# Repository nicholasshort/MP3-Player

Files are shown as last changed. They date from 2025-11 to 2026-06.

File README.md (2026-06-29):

# MP3 Player

This is a simple MP3 player designed to be small, lightweight, and long-lasting. The goal is something I can bring on runs, hikes, or long trips that provides 24+ hours of music on a single charge with wired headphones. Firmware is currently in the works, with low level hardware drivers completed.

Assembled board

## Block diagram

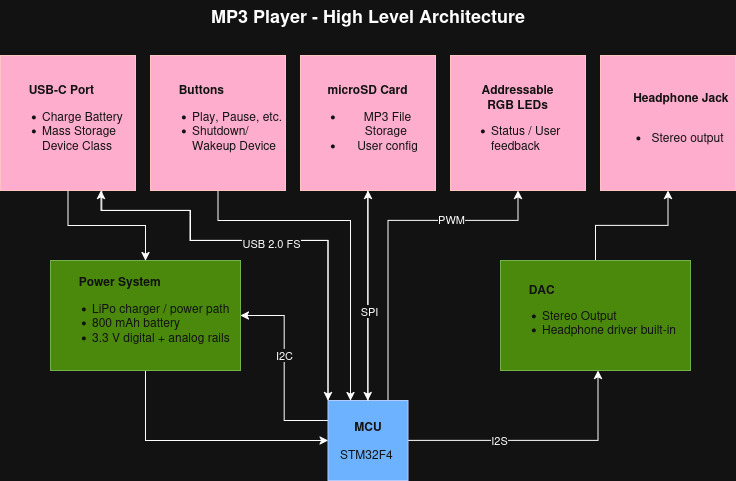
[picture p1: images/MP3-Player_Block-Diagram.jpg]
Block diagram


## Hardware

- **MCU**: STM32F411CEU6 (Cortex-M4F @ 100 MHz, USB OTG FS)
- **DAC**: TI TAD5242 stereo DAC over I²S, 3.5 mm headphone jack
- **Storage**: microSD card (SPI)
- **Power**: USB-C input, TI BQ24259 Li-ion charger, dual TPS7A20 LDOs for analog/digital rails
- **Controls**: 4 tactile switches (PWR, MENU, PLAY, NEXT), 2 × WS2812B-2020 RGB LEDs
- **PCB**: 4-layer, 50 × 50 mm, KiCad

## Repository layout

- `MP3-Player-PCB/` — KiCad project (schematics, board, libraries)
- `MP3-Player-PCB/Manufacturing/` — Gerbers, BOM, and pick-and-place files for JLCPCB
- `MP3-Player-Firmware/` — STM32CubeIDE project
- `images/` — Photos of the board

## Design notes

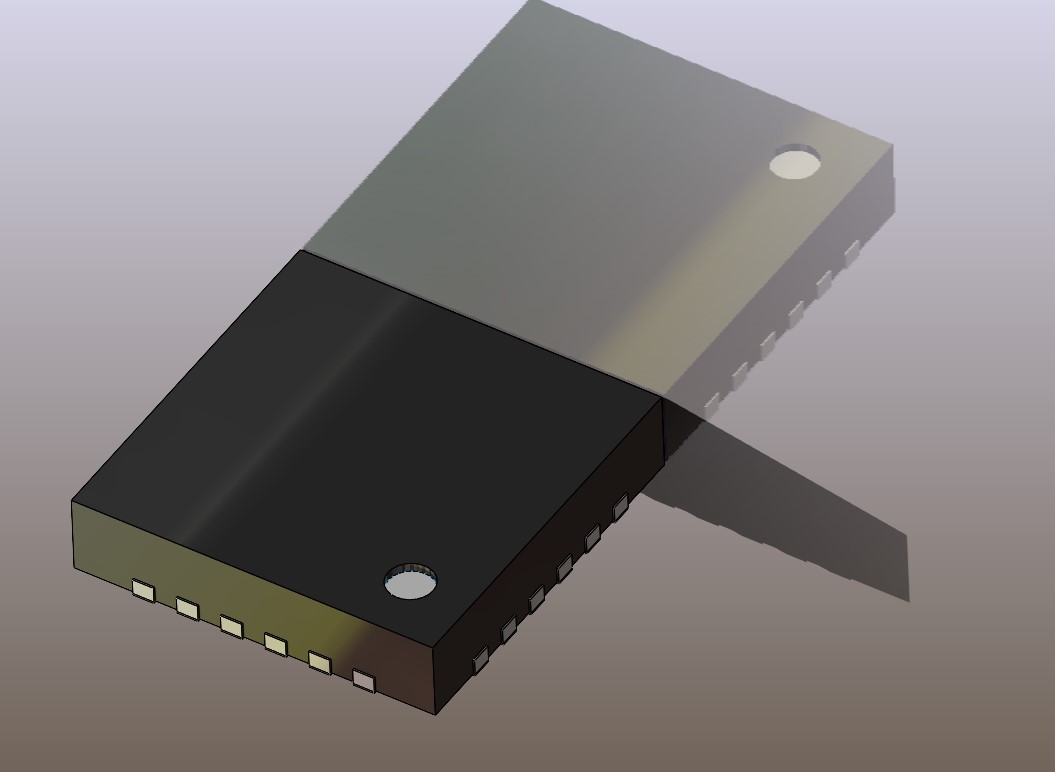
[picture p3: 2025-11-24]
MP3-Player-PCB/3D Models/qfn-24-1.snapshot.1/QFN 24.jpg

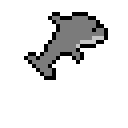
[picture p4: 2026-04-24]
MP3-Player-PCB/Silkscreen Images/Bluesk.png

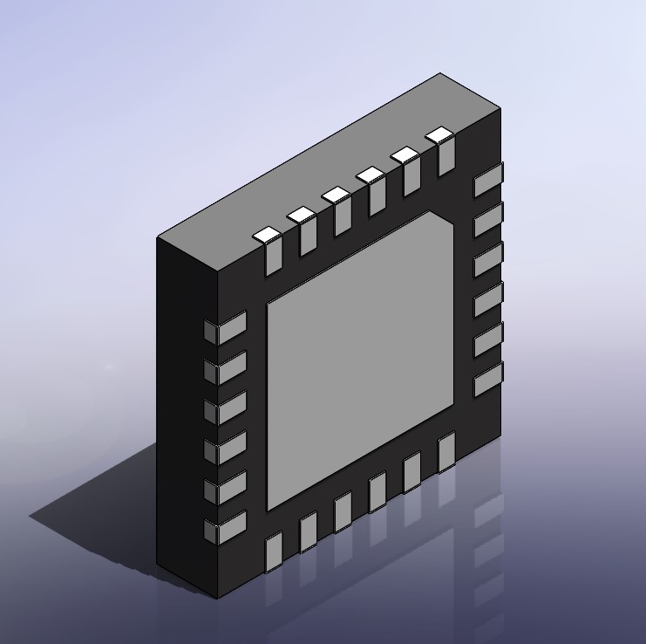
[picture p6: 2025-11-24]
MP3-Player-PCB/3D Models/qfn-24-1.snapshot.1/OFN24.jpg

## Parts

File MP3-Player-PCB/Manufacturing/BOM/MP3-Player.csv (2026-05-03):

Reference | Qty | Footprint | Value | JLCPCB Part #
Y101 | 1 | Crystal:Crystal_SMD_3225-4Pin_3.2x2.5mm | 8MHz | C518154
U401 | 1 | MP3-Player_Footprint_Libraries:TAD5242 | TAD5242 | C42414591
U301,U403 | 2 | Package_TO_SOT_SMD:SOT-23-6 | TPD4E1U06 | C124691
U203,U204 | 2 | Package_TO_SOT_SMD:SOT-23-5 | TPS7A2033PDBVR | C2862740
U202 | 1 | Package_TO_SOT_SMD:SOT-23-6 | USBLC6-2SC6 | C7519
U201 | 1 | Package_DFN_QFN:VQFN-24-1EP_4x4mm_P0.5mm_EP2.5x2.5mm | BQ24259 | C473366
U101 | 1 | Package_DFN_QFN:QFN-48-1EP_7x7mm_P0.5mm_EP5.6x5.6mm | STM32F411CEUx | C2054095
TH201 | 1 | Resistor_SMD:R_0603_1608Metric | NTC | C700814
SW301,SW302,SW303,SW304 | 4 | MP3-Player_Footprint_Libraries:ZX-QC66 | ZX-QC66-10.0TP | C7470162
R305,R306,R307 | 3 | Resistor_SMD:R_0402_1005Metric | 0R | C17168
R217 | 1 | Resistor_SMD:R_0402_1005Metric | 31.6k | C11463
R216 | 1 | Resistor_SMD:R_0402_1005Metric | 200k | C25764
R214 | 1 | Resistor_SMD:R_0402_1005Metric | 100k | C25741
R209,R210,R213,R215,R301,R302,R303,R304,R308,R310,R311,R312,R315 | 13 | Resistor_SMD:R_0402_1005Metric | 56k | C25796
R208 | 1 | Resistor_SMD:R_0402_1005Metric | 316R | C247119
R207 | 1 | Resistor_SMD:R_0402_1005Metric | 5.23k | C25907
R205,R206 | 2 | Resistor_SMD:R_0402_1005Metric | 5.1k | C25905
R202,R203,R204,R309,R313,R314 | 6 | Resistor_SMD:R_0402_1005Metric | 220k | C25546
R103,R104 | 2 | Resistor_SMD:R_0402_1005Metric | 1k | C11702
R102,R201 | 2 | Resistor_SMD:R_0603_1608Metric | 0R | C15402
R101,R211,R212 | 3 | Resistor_SMD:R_0402_1005Metric | 10k | C25744
Q302,Q305 | 2 | Package_TO_SOT_SMD:SOT-23 | 2N7002H | C3290631
Q301,Q303,Q304 | 3 | Package_TO_SOT_SMD:SOT-23 | AO3401A | C15127
L201 | 1 | Inductor_SMD:L_Sunlord_SWPA3015S | 1u | C43388
J402 | 1 | MP3-Player_Footprint_Libraries:PJ-320B | PJ-320B | C18594
J301 | 1 | MP3-Player_Footprint_Libraries:TF-015 | Micro_SD_Card_Det1 | C113206
J202 | 1 | Connector_USB:USB_C_Receptacle_HRO_TYPE-C-31-M-12 | USB_C_Receptacle_USB2.0_16P | C165948
J201 | 1 | Connector_Molex:Molex_PicoBlade_53048-0210_1x02_P1.25mm_Horizontal | Conn_01x02_Socket | C505099
FB201 | 1 | Inductor_SMD:L_0805_2012Metric | 120R | C5671
D301,D302 | 2 | LED_SMD:LED_WS2812B-2020_PLCC4_2.0x2.0mm | WS2812B-2020 | C965555
D102 | 1 | LED_SMD:LED_0402_1005Metric | BLUE | C131223
D101 | 1 | LED_SMD:LED_0402_1005Metric | GREEN | C74338
C205,C206,C207,C208,C210,C214,C215,C216,C217 | 9 | Capacitor_SMD:C_0805_2012Metric | 10u | C15850
C204 | 1 | Capacitor_SMD:C_0402_1005Metric | 47n | C82219
C203,C209,C211,C212,C213,C301,C304,C305,C401,C404,C405,C406 | 12 | Capacitor_SMD:C_0603_1608Metric | 10u | C19702
C113,C114 | 2 | Capacitor_SMD:C_0603_1608Metric | 10p | C162202
C102,C103,C104,C105,C106,C107,C108,C109,C110,C111,C112,C201,C202,C302,C303,C402,C403,C407 | 18 | Capacitor_SMD:C_0402_1005Metric | 100n | C1525
C101,C115 | 2 | Capacitor_SMD:C_0603_1608Metric | 4.7u | C1705

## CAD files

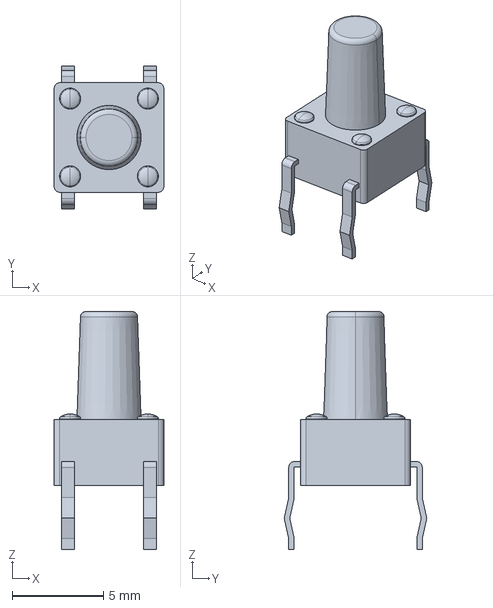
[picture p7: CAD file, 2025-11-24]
MP3-Player-PCB/3D Models/1_1825910_4/c-1-1825910-4-c-3d.stp
5.99 x 7.80 x 13.0 mm

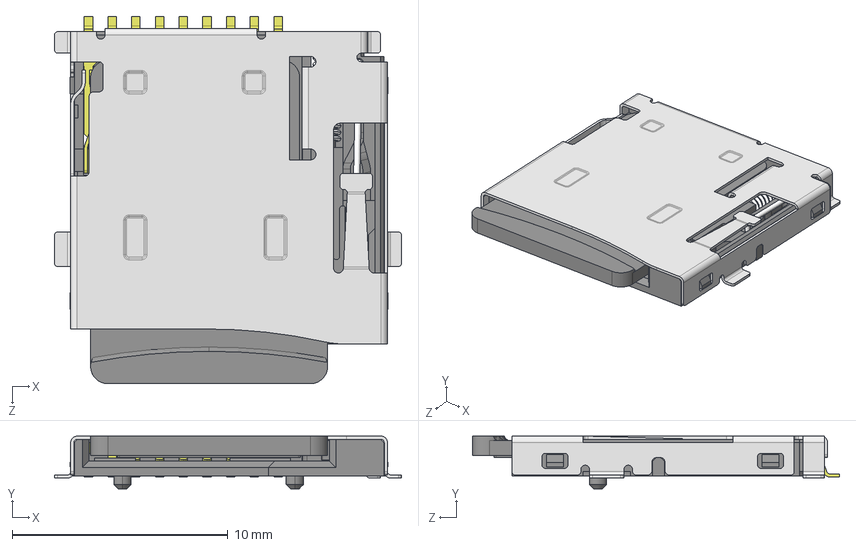
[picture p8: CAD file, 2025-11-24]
MP3-Player-PCB/3D Models/microsd-socket-slot-like-tfp09-2-12b-tf-01a-etc-1.snapshot.1/MicroSD_Socket.STEP
16.1 x 2.45 x 17.0 mm
Case^MicroSD_Socket
Insert^MicroSD_Socket
Brace^MicroSD_Socket
Spring^MicroSD_Socket
Lid^MicroSD_Socket
Pin_Middle^MicroSD_Socket x 5
Pin_Short^MicroSD_Socket
Pin_Long^MicroSD_Socket x 2
MicroSD_Card^MicroSD_Socket
Pin_CardIn^MicroSD_Socket

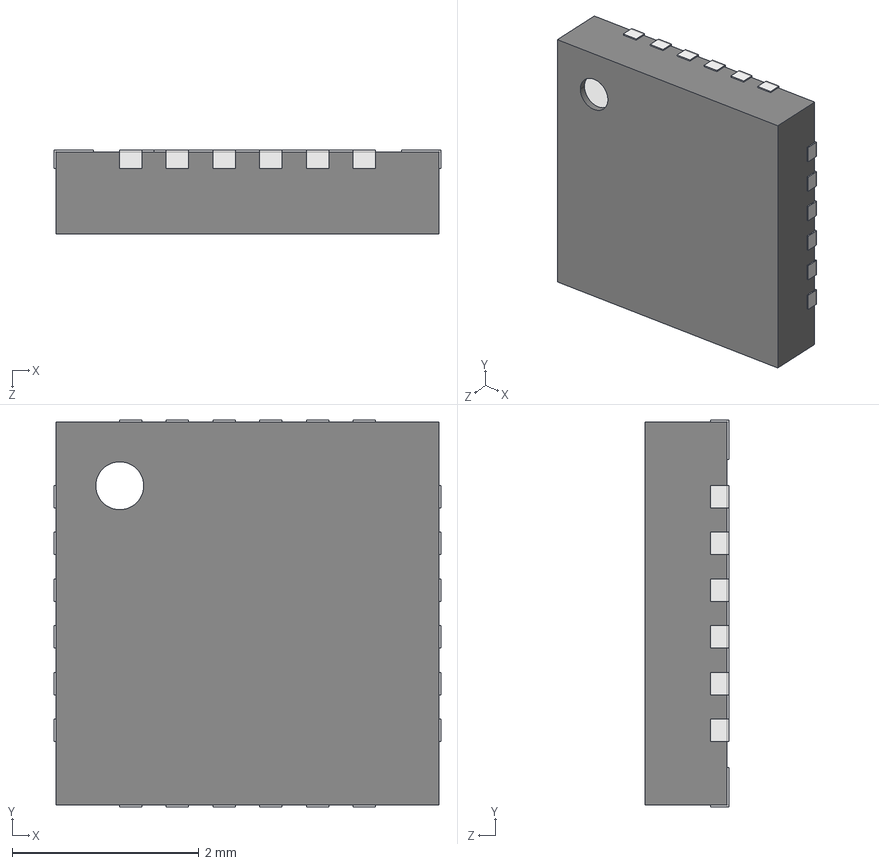
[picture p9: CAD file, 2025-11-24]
MP3-Player-PCB/3D Models/qfn-24-1.snapshot.1/QFN 24.STEP
4.14 x 4.14 x 0.9 mm
Open_CASCADE_STEP_translator_6.8_11.2.1.step_Varsay考an
Open_CASCADE_STEP_translator_6.8_11.4.1.step_Varsay考an x 24
Open_CASCADE_STEP_translator_6.8_11.1.step_Varsay考an
Thermal_Shape.step_Varsay考an

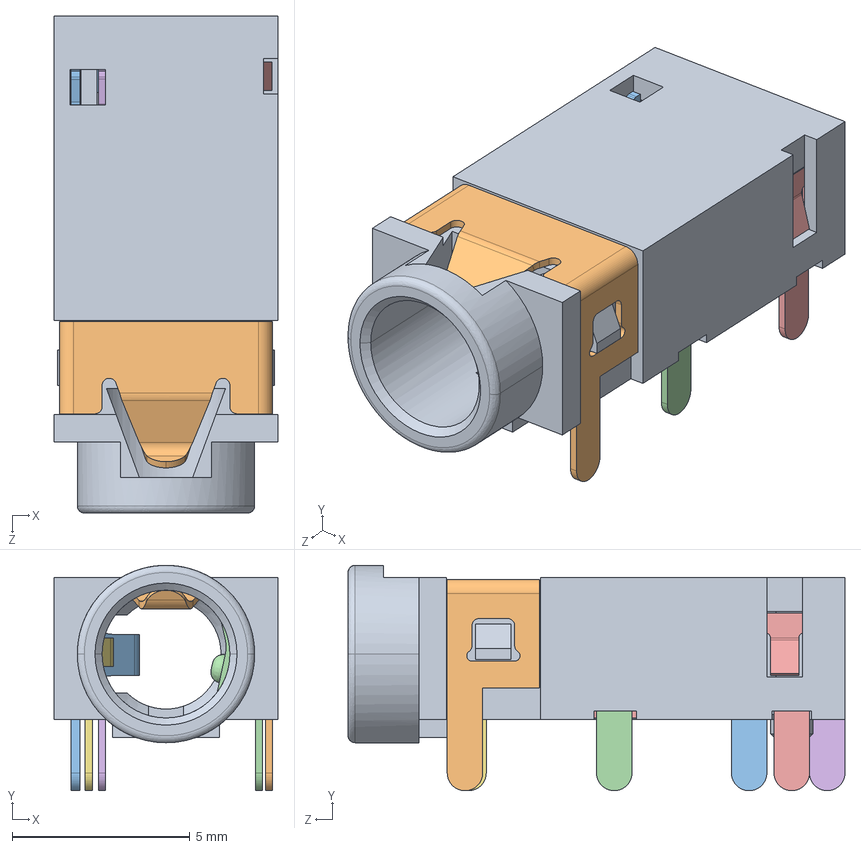
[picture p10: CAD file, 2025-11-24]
MP3-Player-PCB/3D Models/Similar Audio Jack Connector/54-00176.STEP
6.30 x 6.35 x 14.0 mm
54-00176_insulator
54-00176_#1
54-00176_#4
54-00176_#3
54-00176_#6
54-00176_#5
54-00176_#2

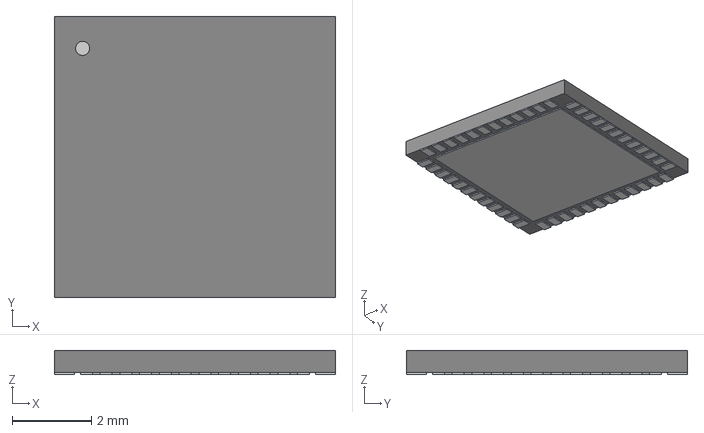
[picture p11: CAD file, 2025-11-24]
MP3-Player-PCB/3D Models/STM32F411CEU6/UFQFPN-48_7X7X0P55MM.step
7.11 x 7.11 x 0.612 mm

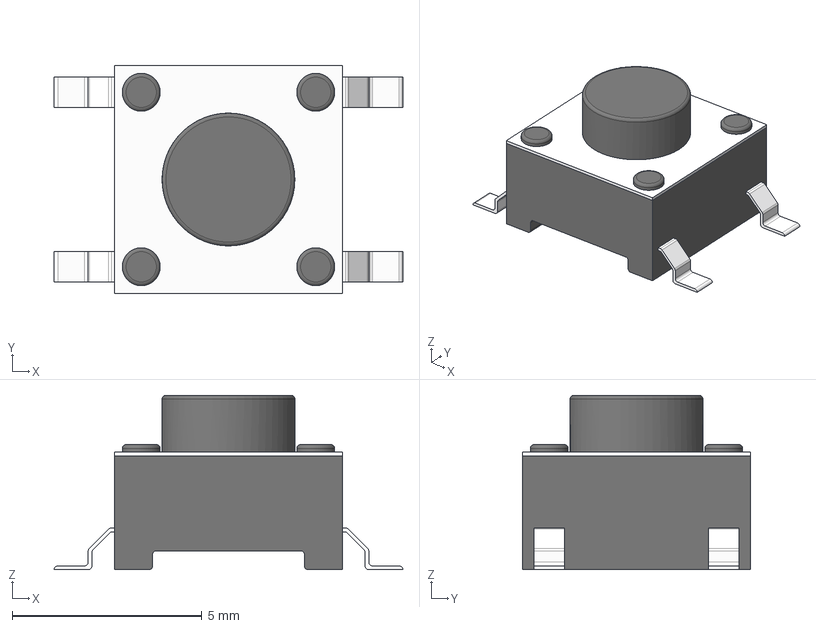
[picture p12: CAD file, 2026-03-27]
MP3-Player-PCB/3D Models/tact-switch-smd-6x6mm-x-4-5mm-1.snapshot.1/tact switch SMD 6x6 mm x 4,5mm.step
9.20 x 6.00 x 4.60 mm

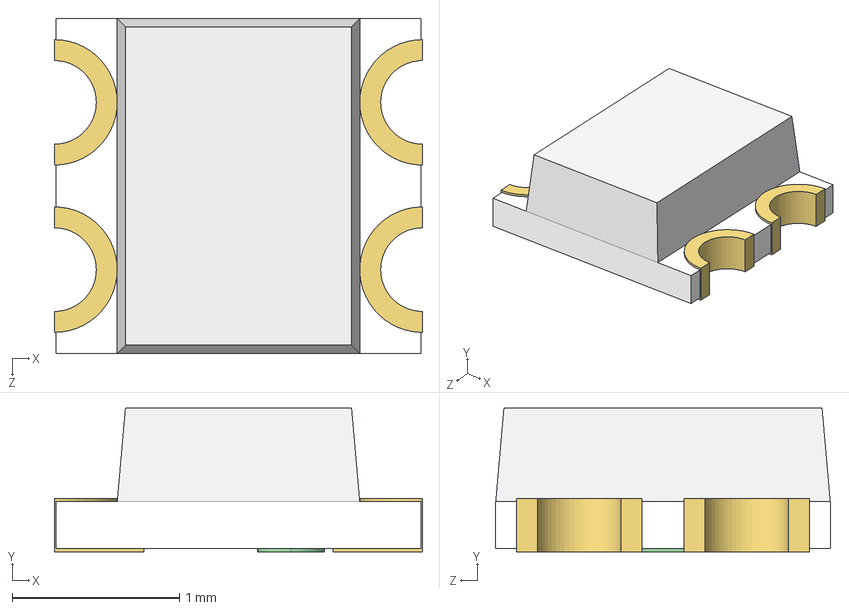
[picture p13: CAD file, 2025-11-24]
MP3-Player-PCB/3D Models/ws2812-2020-1.snapshot.4/WS2812-2020.STEP
2.20 x 0.86 x 2.00 mm

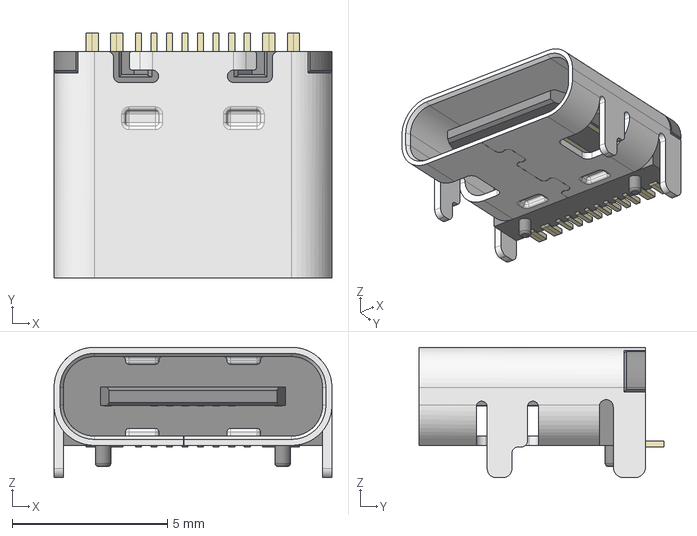
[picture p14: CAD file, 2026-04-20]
MP3-Player-PCB/3D Models/HRO_TYPE-C-31-M-12.step
8.95 x 7.90 x 4.20 mm

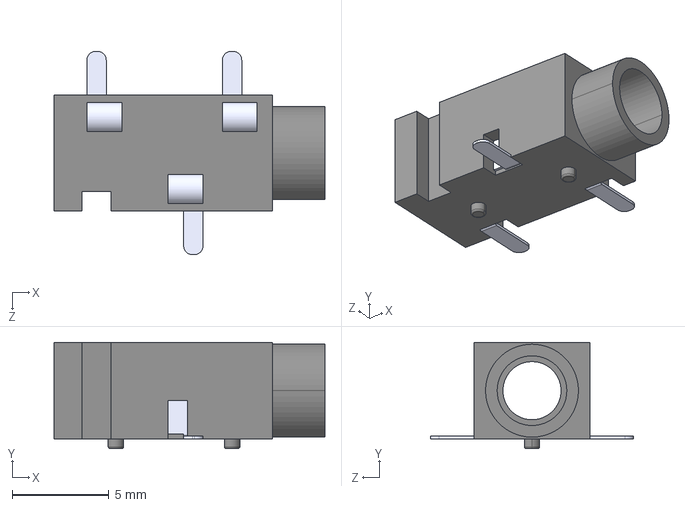
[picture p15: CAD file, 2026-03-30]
MP3-Player-PCB/3D Models/PJ-320B--3DModel-STEP-56544.STEP
14.0 x 5.50 x 10.5 mm

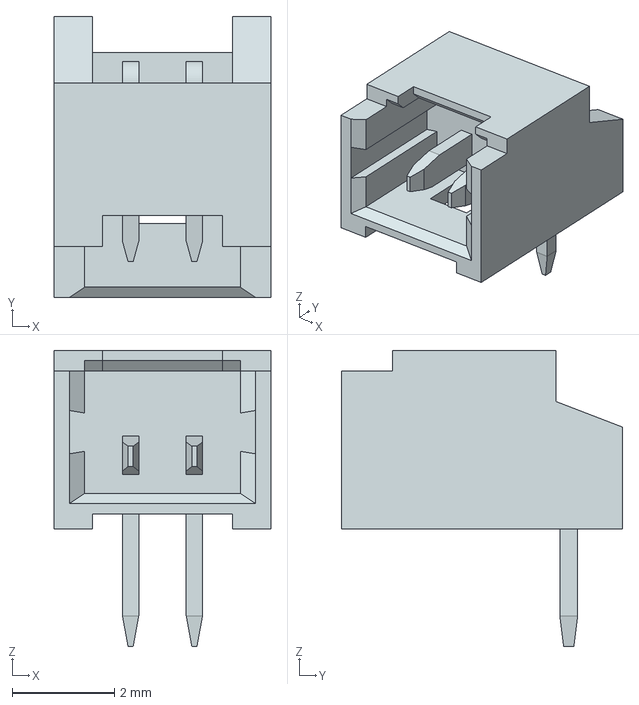
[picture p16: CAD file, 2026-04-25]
MP3-Player-PCB/3D Models/530480210.stp
4.25 x 5.50 x 5.80 mm

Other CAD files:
MP3-Player-PCB/3D Models/ws2812-2020-1.snapshot.4/WS2812-2020.SLDPRT

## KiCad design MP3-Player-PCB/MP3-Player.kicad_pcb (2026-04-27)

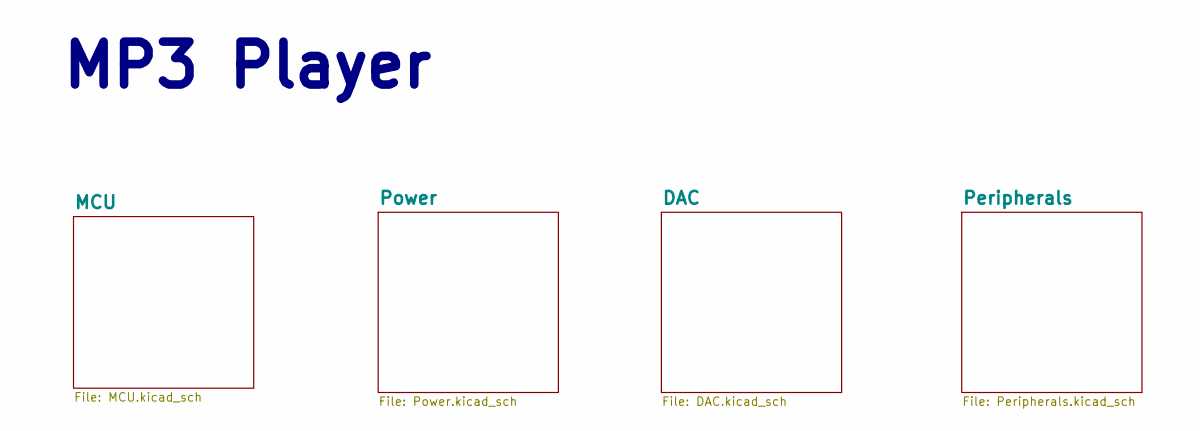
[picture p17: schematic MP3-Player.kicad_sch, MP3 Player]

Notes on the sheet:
MP3 Player

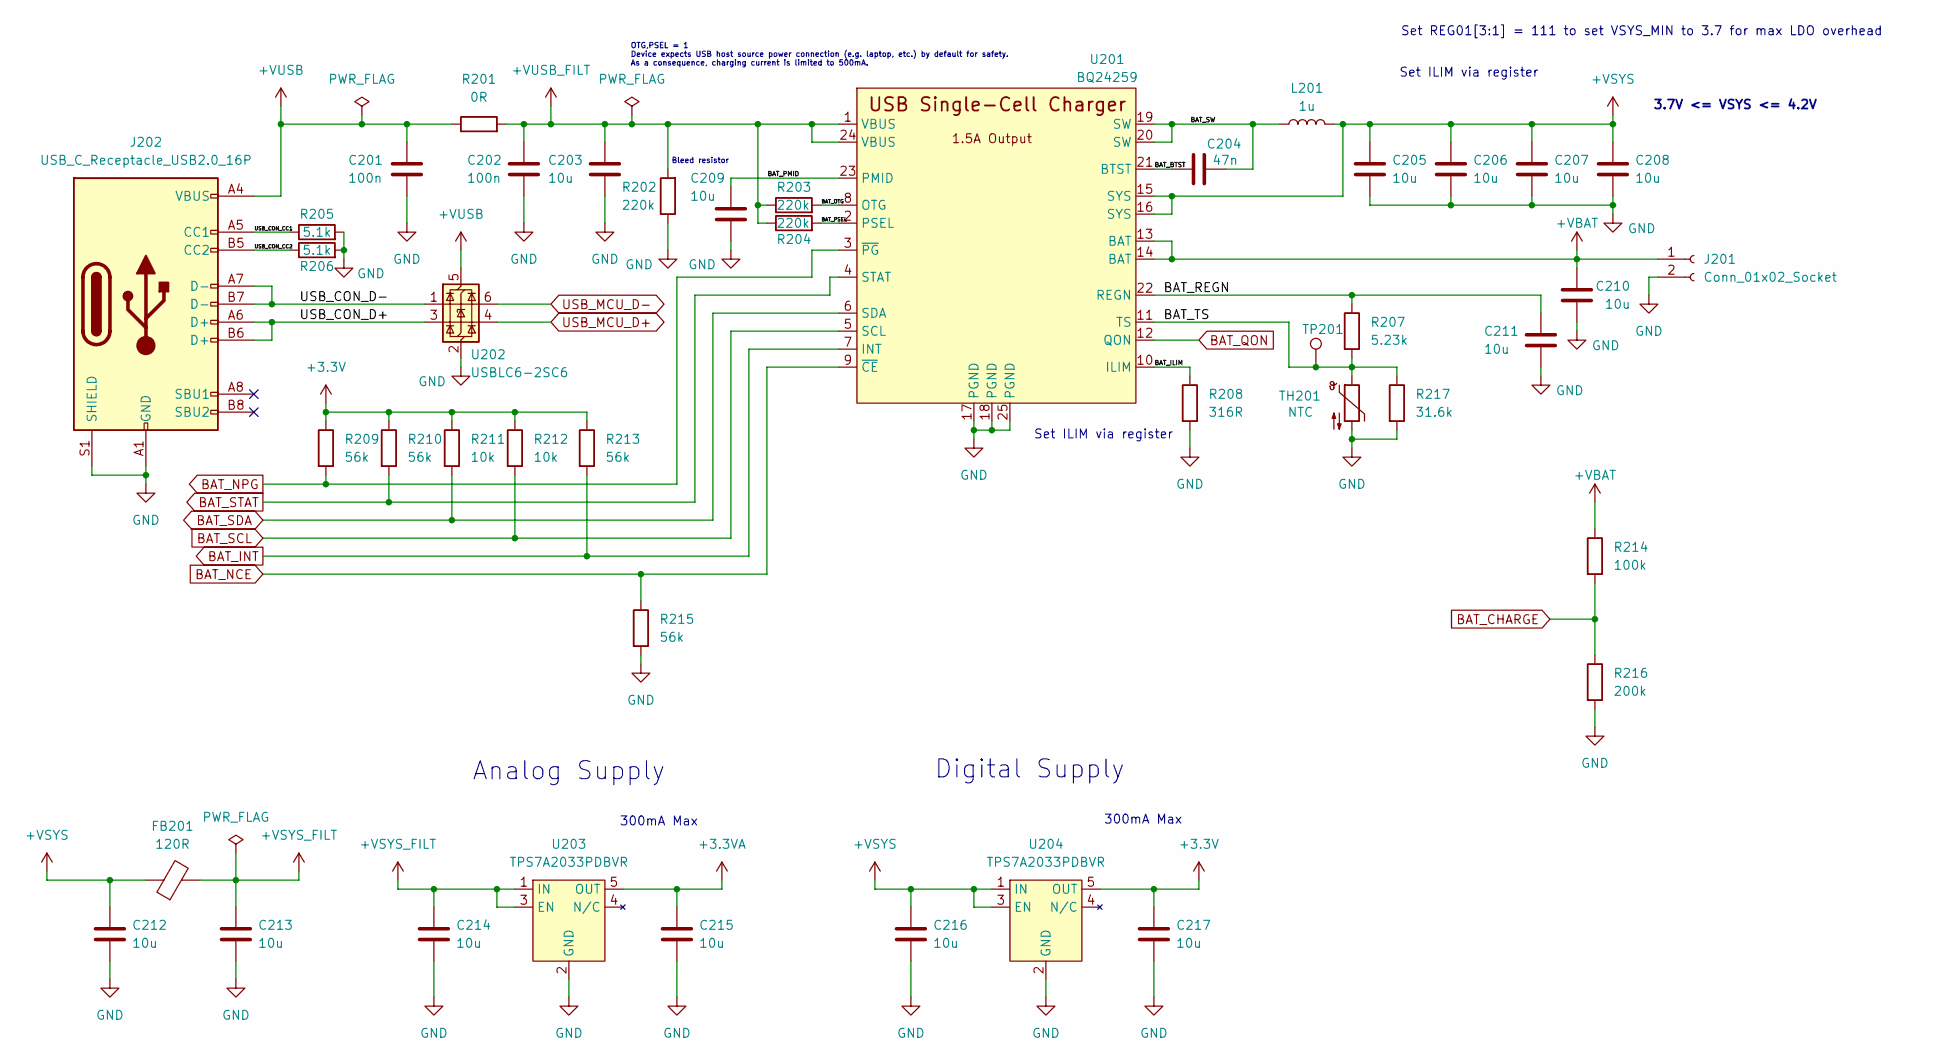
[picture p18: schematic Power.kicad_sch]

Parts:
C201, C202: 100n; C_0402_1005Metric; JLCPCB Part # C1525
C203, C209, C211, C212, C213: 10u; C_0603_1608Metric; JLCPCB Part # C19702
C204: 47n; C_0402_1005Metric; JLCPCB Part # C82219
C205, C206, C207, C208, C210, C214, C215, C216, C217: 10u; C_0805_2012Metric; JLCPCB Part # C15850
FB201: 120R; L_0805_2012Metric; JLCPCB Part # C5671
J201: Conn_01x02_Socket; Molex_PicoBlade_53048-0210_1x02_P1.25mm_Horizontal; JLCPCB Part # C505099
J202: USB_C_Receptacle_USB2.0_16P; USB_C_Receptacle_HRO_TYPE-C-31-M-12; JLCPCB Part # C165948
L201: 1u; L_Sunlord_SWPA3015S; JLCPCB Part # C43388
R201: 0R; R_0603_1608Metric; JLCPCB Part # C15402
R202, R203, R204: 220k; R_0402_1005Metric; JLCPCB Part # C25546
R205, R206: 5.1k; R_0402_1005Metric; JLCPCB Part # C25905
R207: 5.23k; R_0402_1005Metric; JLCPCB Part # C25907
R208: 316R; R_0402_1005Metric; JLCPCB Part # C247119
R209, R210, R213, R215: 56k; R_0402_1005Metric; JLCPCB Part # C25796
R211, R212: 10k; R_0402_1005Metric; JLCPCB Part # C25744
R214: 100k; R_0402_1005Metric; JLCPCB Part # C25741
R216: 200k; R_0402_1005Metric; JLCPCB Part # C25764
R217: 31.6k; R_0402_1005Metric; JLCPCB Part # C11463
TH201: NTC; R_0603_1608Metric; JLCPCB Part # C700814
TP201: TestPoint; TestPoint_Pad_1.0x1.0mm
U201: BQ24259; VQFN-24-1EP_4x4mm_P0.5mm_EP2.5x2.5mm; JLCPCB Part # C473366
U202: USBLC6-2SC6; SOT-23-6; JLCPCB Part # C7519
U203, U204: TPS7A2033PDBVR; SOT-23-5; JLCPCB Part # C2862740

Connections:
+3.3V: C217.1, R209.1, R210.1, R211.1, R212.1, R213.1, U204.5 (OUT); also elsewhere on the board
+3.3VA: C215.1, U203.5 (OUT); also elsewhere on the board
+VBAT: C210.1, J201.1, R214.1, U201.13 (BAT), U201.14 (BAT); also elsewhere on the board
+VSYS: C205.1, C206.1, C207.1, C208.1, C212.1, C216.1, FB201.1, L201.2, U201.15 (SYS), U201.16 (SYS), U204.1 (IN), U204.3 (EN); also elsewhere on the board
+VSYS_FILT: C213.1, C214.1, FB201.2, U203.1 (IN), U203.3 (EN)
+VUSB: C201.1, J202.A4 (VBUS), J202.A9 (VBUS), J202.B4 (VBUS), J202.B9 (VBUS), R201.1, U202.5 (VBUS)
+VUSB_FILT: C202.1, C203.1, R201.2, R202.2, R203.1, R204.1, U201.1 (VBUS), U201.24 (VBUS)
/Power/BAT_BTST: C204.1, U201.21 (BTST)
/Power/BAT_ILIM: R208.1, U201.10 (ILIM)
/Power/BAT_OTG: R203.2, U201.8 (OTG)
/Power/BAT_PMID: C209.1, U201.23 (PMID)
/Power/BAT_PSEL: R204.2, U201.2 (PSEL)
/Power/BAT_REGN: C211.1, R207.1, U201.22 (REGN)
/Power/BAT_SW: C204.2, L201.1, U201.19 (SW), U201.20 (SW)
/Power/BAT_TS: R207.2, R217.1, TH201.1, TP201.1, U201.11 (TS)
/Power/USB_CON_CC1: J202.A5 (CC1), R205.1
/Power/USB_CON_CC2: J202.B5 (CC2), R206.1
/Power/USB_CON_D+: J202.A6 (D+), J202.B6 (D+), U202.3 (I/O2)
/Power/USB_CON_D-: J202.A7 (D-), J202.B7 (D-), U202.1 (I/O1)
BAT_CHARGE: R214.2, R216.1; also elsewhere on the board
BAT_INT: R213.2, U201.7 (INT); also elsewhere on the board
BAT_NCE: R215.1, U201.9 (~CE); also elsewhere on the board
BAT_NPG: R209.2, U201.3 (~PG); also elsewhere on the board
BAT_QON: U201.12 (QON); also elsewhere on the board
BAT_SCL: R212.2, U201.5 (SCL); also elsewhere on the board
BAT_SDA: R211.2, U201.6 (SDA); also elsewhere on the board
BAT_STAT: R210.2, U201.4 (STAT); also elsewhere on the board
GND: C201.2, C202.2, C203.2, C205.2, C206.2, C207.2, C208.2, C209.2, C210.2, C211.2, C212.2, C213.2, C214.2, C215.2, C216.2, C217.2, J201.2, J202.A1 (GND), J202.A12 (GND), J202.B1 (GND), J202.B12 (GND), J202.S1 (SHIELD), R202.1, R205.2, R206.2, R208.2, R215.2, R216.2, R217.2, TH201.2, U201.17 (PGND), U201.18 (PGND), U201.25 (PGND), U202.2 (GND), U203.2 (GND), U204.2 (GND); also elsewhere on the board
USB_MCU_D+: U202.4 (I/O2); also elsewhere on the board
USB_MCU_D-: U202.6 (I/O1); also elsewhere on the board

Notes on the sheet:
Analog Supply
Set ILIM via register
Bleed resistor
300mA Max
Digital Supply
OTG,PSEL = 1 Device expects USB host source power connection (e.g. laptop, etc.) by default for safety. As a consequence, charging current is limited to 500mA.
3.7V <= VSYS <= 4.2V
Set REG01[3:1] = 111 to set VSYS_MIN to 3.7 for max LDO overhead

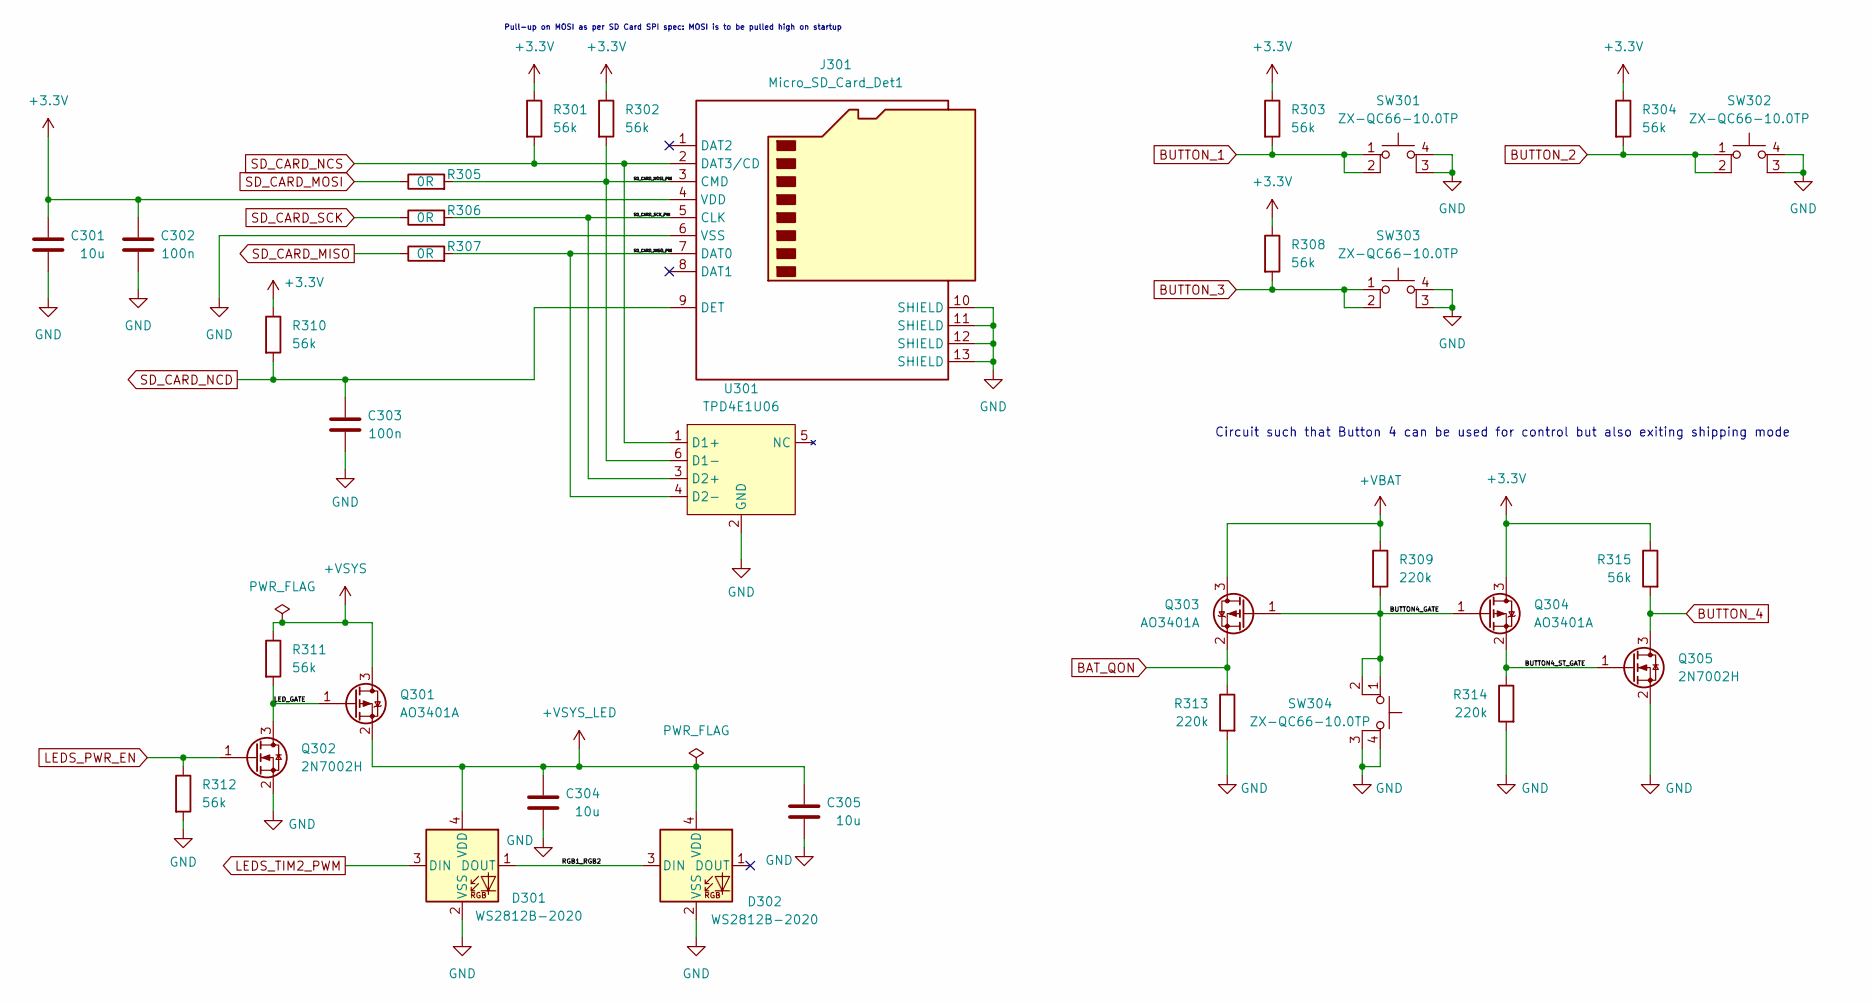
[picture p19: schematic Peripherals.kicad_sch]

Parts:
C301, C304, C305: 10u; C_0603_1608Metric; JLCPCB Part # C19702
C302, C303: 100n; C_0402_1005Metric; JLCPCB Part # C1525
D301, D302: WS2812B-2020; LED_WS2812B-2020_PLCC4_2.0x2.0mm; JLCPCB Part # C965555
J301: Micro_SD_Card_Det1; TF-015; JLCPCB Part # C113206
Q301, Q303, Q304: AO3401A; SOT-23; JLCPCB Part # C15127
Q302, Q305: 2N7002H; SOT-23; JLCPCB Part # C3290631
R301, R302, R303, R304, R308, R310, R311, R312, R315: 56k; R_0402_1005Metric; JLCPCB Part # C25796
R305, R306, R307: 0R; R_0402_1005Metric; JLCPCB Part # C17168
R309, R313, R314: 220k; R_0402_1005Metric; JLCPCB Part # C25546
SW301, SW302, SW303, SW304: ZX-QC66-10.0TP; ZX-QC66; JLCPCB Part # C7470162
U301: TPD4E1U06; SOT-23-6; JLCPCB Part # C124691

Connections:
+3.3V: C301.1, C302.1, J301.4 (VDD), Q304.3 (D), R301.1, R302.1, R303.1, R304.1, R308.1, R310.1, R315.1; also elsewhere on the board
+VBAT: Q303.3 (D), R309.1; also elsewhere on the board
+VSYS: Q301.3 (D), R311.1; also elsewhere on the board
+VSYS_LED: C304.1, C305.1, D301.4 (VDD), D302.4 (VDD), Q301.2 (S)
/Peripherals/BUTTON4_GATE: Q303.1 (G), Q304.1 (G), R309.2, SW304.1, SW304.2
/Peripherals/BUTTON4_ST_GATE: Q304.2 (S), Q305.1 (G), R314.1
/Peripherals/LED_GATE: Q301.1 (G), Q302.3 (D), R311.2
/Peripherals/RGB1_RGB2: D301.1 (DOUT), D302.3 (DIN)
/Peripherals/SD_CARD_MISO_PIN: J301.7 (DAT0), R307.2, U301.4 (D2-)
/Peripherals/SD_CARD_MOSI_PIN: J301.3 (CMD), R302.2, R305.2, U301.6 (D1-)
/Peripherals/SD_CARD_SCK_PIN: J301.5 (CLK), R306.2, U301.3 (D2+)
BAT_QON: Q303.2 (S), R313.1; also elsewhere on the board
BUTTON_1: R303.2, SW301.1, SW301.2; also elsewhere on the board
BUTTON_2: R304.2, SW302.1, SW302.2; also elsewhere on the board
BUTTON_3: R308.2, SW303.1, SW303.2; also elsewhere on the board
BUTTON_4: Q305.3 (D), R315.2; also elsewhere on the board
GND: C301.2, C302.2, C303.2, C304.2, C305.2, D301.2 (VSS), D302.2 (VSS), J301.6 (VSS), J301.10 (SHIELD), J301.11 (SHIELD), J301.12 (SHIELD), J301.13 (SHIELD), Q302.2 (S), Q305.2 (S), R312.2, R313.2, R314.2, SW301.3 (K), SW301.4 (A), SW302.3 (K), SW302.4 (A), SW303.3 (K), SW303.4 (A), SW304.3 (K), SW304.4 (A), U301.2 (GND); also elsewhere on the board
LEDS_PWR_EN: Q302.1 (G), R312.1; also elsewhere on the board
LEDS_TIM2_PWM: D301.3 (DIN); also elsewhere on the board
SD_CARD_MISO: R307.1; also elsewhere on the board
SD_CARD_MOSI: R305.1; also elsewhere on the board
SD_CARD_NCD: C303.1, J301.9 (DET), R310.2; also elsewhere on the board
SD_CARD_NCS: J301.2 (DAT3/CD), R301.2, U301.1 (D1+); also elsewhere on the board
SD_CARD_SCK: R306.1; also elsewhere on the board

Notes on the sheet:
Circuit such that Button 4 can be used for control but also exiting shipping mode
Pull-up on MOSI as per SD Card SPI spec: MOSI is to be pulled high on startup

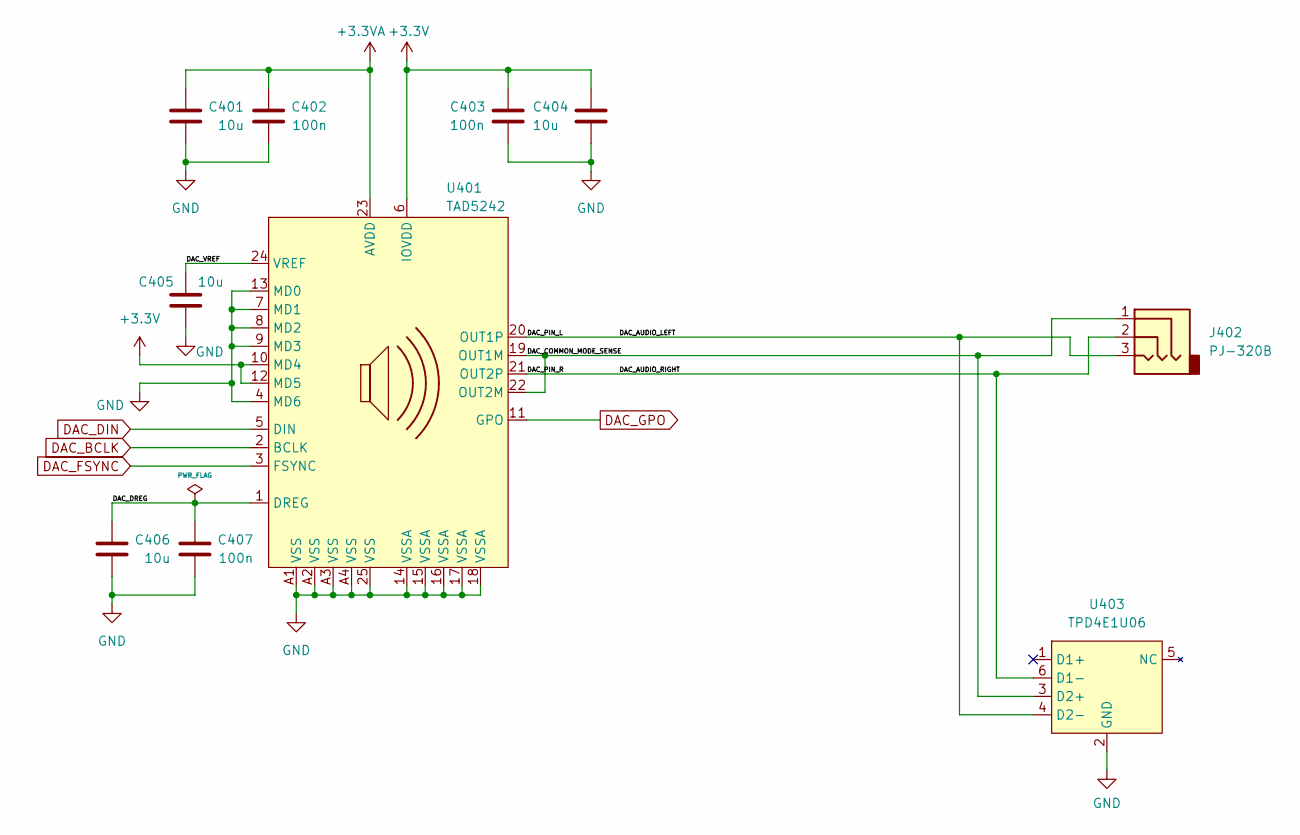
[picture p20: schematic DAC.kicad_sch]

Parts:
C401, C404, C405, C406: 10u; C_0603_1608Metric; JLCPCB Part # C19702
C402, C403, C407: 100n; C_0402_1005Metric; JLCPCB Part # C1525
J402: PJ-320B; JLCPCB Part # C18594
U401: TAD5242; JLCPCB Part # C42414591
U403: TPD4E1U06; SOT-23-6; JLCPCB Part # C124691

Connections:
+3.3V: C403.1, C404.1, U401.6 (IOVDD), U401.10 (MD4), U401.12 (MD5); also elsewhere on the board
+3.3VA: C401.1, C402.1, U401.23 (AVDD); also elsewhere on the board
/DAC/DAC_AUDIO_LEFT: J402.3, U401.20 (OUT1P), U403.4 (D2-)
/DAC/DAC_AUDIO_RIGHT: J402.2, U401.21 (OUT2P), U403.6 (D1-)
/DAC/DAC_COMMON_MODE_SENSE: J402.1, U401.19 (OUT1M), U401.22 (OUT2M), U403.3 (D2+)
/DAC/DAC_DREG: C406.1, C407.1, U401.1 (DREG)
/DAC/DAC_VREF: C405.1, U401.24 (VREF)
DAC_BCLK: U401.2 (BCLK); also elsewhere on the board
DAC_DIN: U401.5 (DIN); also elsewhere on the board
DAC_FSYNC: U401.3 (FSYNC); also elsewhere on the board
DAC_GPO: U401.11 (GPO); also elsewhere on the board
GND: C401.2, C402.2, C403.2, C404.2, C405.2, C406.2, C407.2, U401.4 (MD6), U401.7 (MD1), U401.8 (MD2), U401.9 (MD3), U401.13 (MD0), U401.14 (VSSA), U401.15 (VSSA), U401.16 (VSSA), U401.17 (VSSA), U401.18 (VSSA), U401.25 (VSS), U401.A1 (VSS), U401.A2 (VSS), U401.A3 (VSS), U401.A4 (VSS), U403.2 (GND); also elsewhere on the board

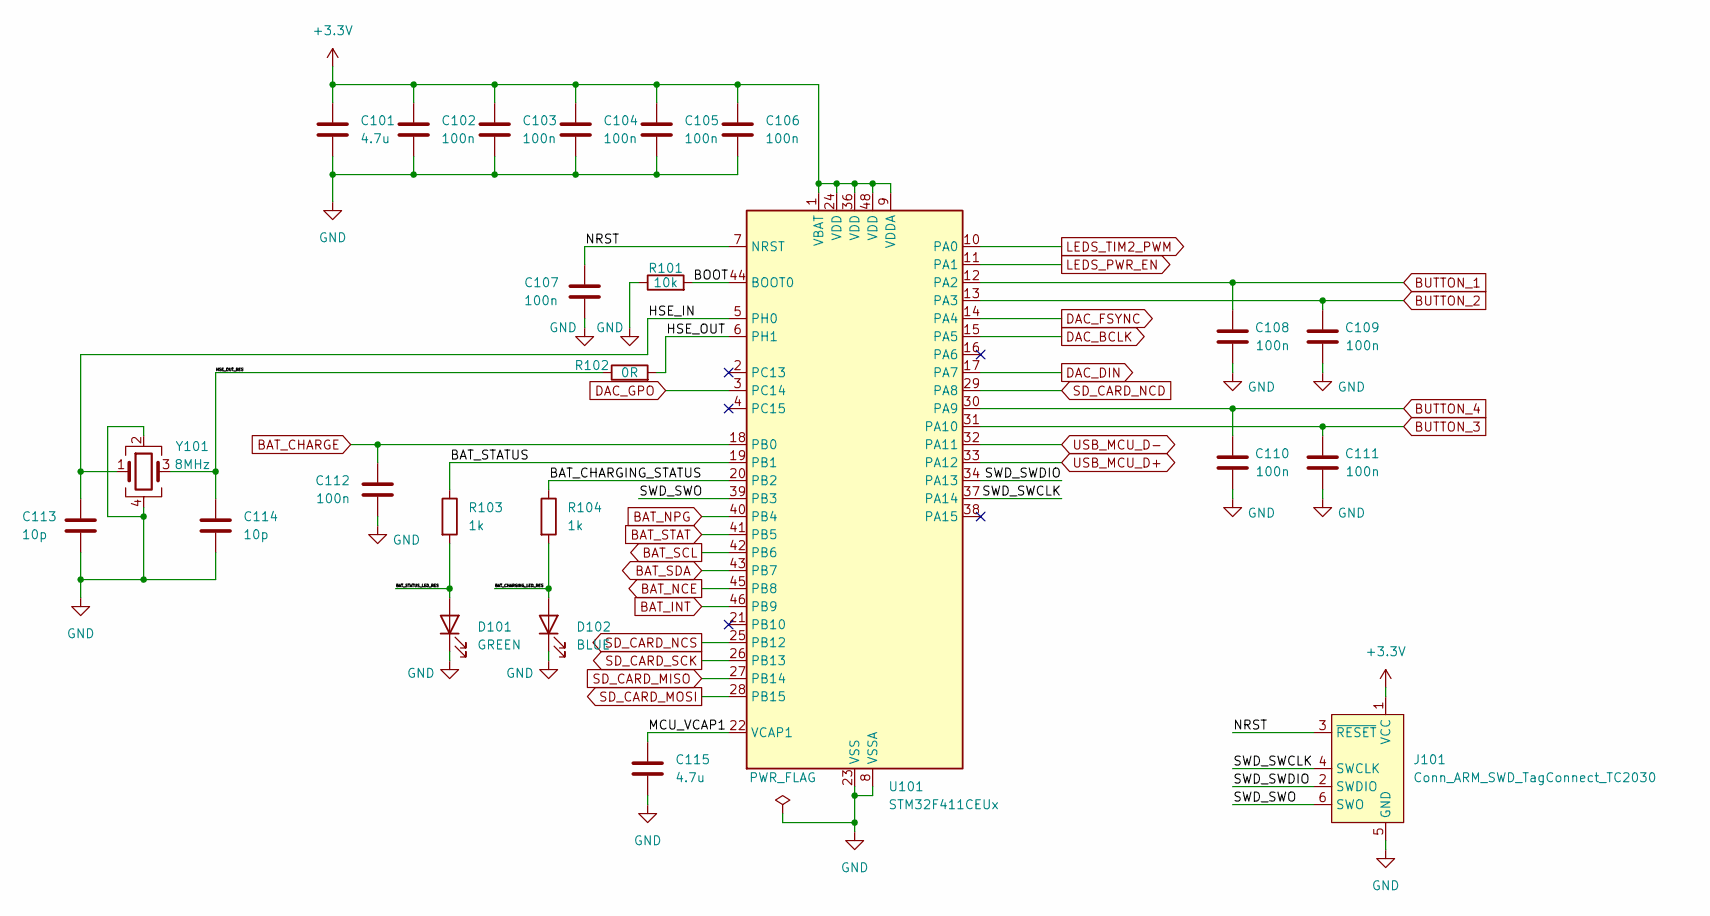
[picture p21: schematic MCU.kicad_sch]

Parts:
C101, C115: 4.7u; C_0603_1608Metric; JLCPCB Part # C1705
C102, C103, C104, C105, C106, C107, C108, C109, C110, C111, C112: 100n; C_0402_1005Metric; JLCPCB Part # C1525
C113, C114: 10p; C_0603_1608Metric; JLCPCB Part # C162202
D101: GREEN; LED_0402_1005Metric; JLCPCB Part # C74338
D102: BLUE; LED_0402_1005Metric; JLCPCB Part # C131223
J101: Conn_ARM_SWD_TagConnect_TC2030; Tag-Connect_TC2030-IDC-FP_2x03_P1.27mm_Vertical
R101: 10k; R_0402_1005Metric; JLCPCB Part # C25744
R102: 0R; R_0603_1608Metric; JLCPCB Part # C15402
R103, R104: 1k; R_0402_1005Metric; JLCPCB Part # C11702
U101: STM32F411CEUx; QFN-48-1EP_7x7mm_P0.5mm_EP5.6x5.6mm; JLCPCB Part # C2054095
Y101: 8MHz; Crystal_SMD_3225-4Pin_3.2x2.5mm; JLCPCB Part # C518154

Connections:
+3.3V: C101.1, C102.1, C103.1, C104.1, C105.1, C106.1, J101.1 (VCC), U101.1 (VBAT), U101.9 (VDDA), U101.24 (VDD), U101.36 (VDD), U101.48 (VDD); also elsewhere on the board
/MCU/BAT_CHARGING_LED_RES: D102.2 (A), R104.2
/MCU/BAT_CHARGING_STATUS: R104.1, U101.20 (PB2)
/MCU/BAT_STATUS: R103.1, U101.19 (PB1)
/MCU/BAT_STATUS_LED_RES: D101.2 (A), R103.2
/MCU/BOOT: R101.2, U101.44 (BOOT0)
/MCU/HSE_IN: C113.1, U101.5 (PH0), Y101.1
/MCU/HSE_OUT: R102.2, U101.6 (PH1)
/MCU/HSE_OUT_RES: C114.1, R102.1, Y101.3
/MCU/MCU_VCAP1: C115.1, U101.22 (VCAP1)
/MCU/NRST: C107.1, J101.3 (~RESET), U101.7 (NRST)
/MCU/SWD_SWCLK: J101.4 (SWCLK), U101.37 (PA14)
/MCU/SWD_SWDIO: J101.2 (SWDIO), U101.34 (PA13)
/MCU/SWD_SWO: J101.6 (SWO), U101.39 (PB3)
BAT_CHARGE: C112.1, U101.18 (PB0); also elsewhere on the board
BAT_INT: U101.46 (PB9); also elsewhere on the board
BAT_NCE: U101.45 (PB8); also elsewhere on the board
BAT_NPG: U101.40 (PB4); also elsewhere on the board
BAT_SCL: U101.42 (PB6); also elsewhere on the board
BAT_SDA: U101.43 (PB7); also elsewhere on the board
BAT_STAT: U101.41 (PB5); also elsewhere on the board
BUTTON_1: C108.1, U101.12 (PA2); also elsewhere on the board
BUTTON_2: C109.1, U101.13 (PA3); also elsewhere on the board
BUTTON_3: C111.1, U101.31 (PA10); also elsewhere on the board
BUTTON_4: C110.1, U101.30 (PA9); also elsewhere on the board
DAC_BCLK: U101.15 (PA5); also elsewhere on the board
DAC_DIN: U101.17 (PA7); also elsewhere on the board
DAC_FSYNC: U101.14 (PA4); also elsewhere on the board
DAC_GPO: U101.3 (PC14); also elsewhere on the board
GND: C101.2, C102.2, C103.2, C104.2, C105.2, C106.2, C107.2, C108.2, C109.2, C110.2, C111.2, C112.2, C113.2, C114.2, C115.2, D101.1 (K), D102.1 (K), J101.5 (GND), R101.1, U101.8 (VSSA), U101.23 (VSS), U101.35 (VSS), U101.47 (VSS), U101.49 (VSS), Y101.2, Y101.4; also elsewhere on the board
LEDS_PWR_EN: U101.11 (PA1); also elsewhere on the board
LEDS_TIM2_PWM: U101.10 (PA0); also elsewhere on the board
SD_CARD_MISO: U101.27 (PB14); also elsewhere on the board
SD_CARD_MOSI: U101.28 (PB15); also elsewhere on the board
SD_CARD_NCD: U101.29 (PA8); also elsewhere on the board
SD_CARD_NCS: U101.25 (PB12); also elsewhere on the board
SD_CARD_SCK: U101.26 (PB13); also elsewhere on the board
USB_MCU_D+: U101.33 (PA12); also elsewhere on the board
USB_MCU_D-: U101.32 (PA11); also elsewhere on the board

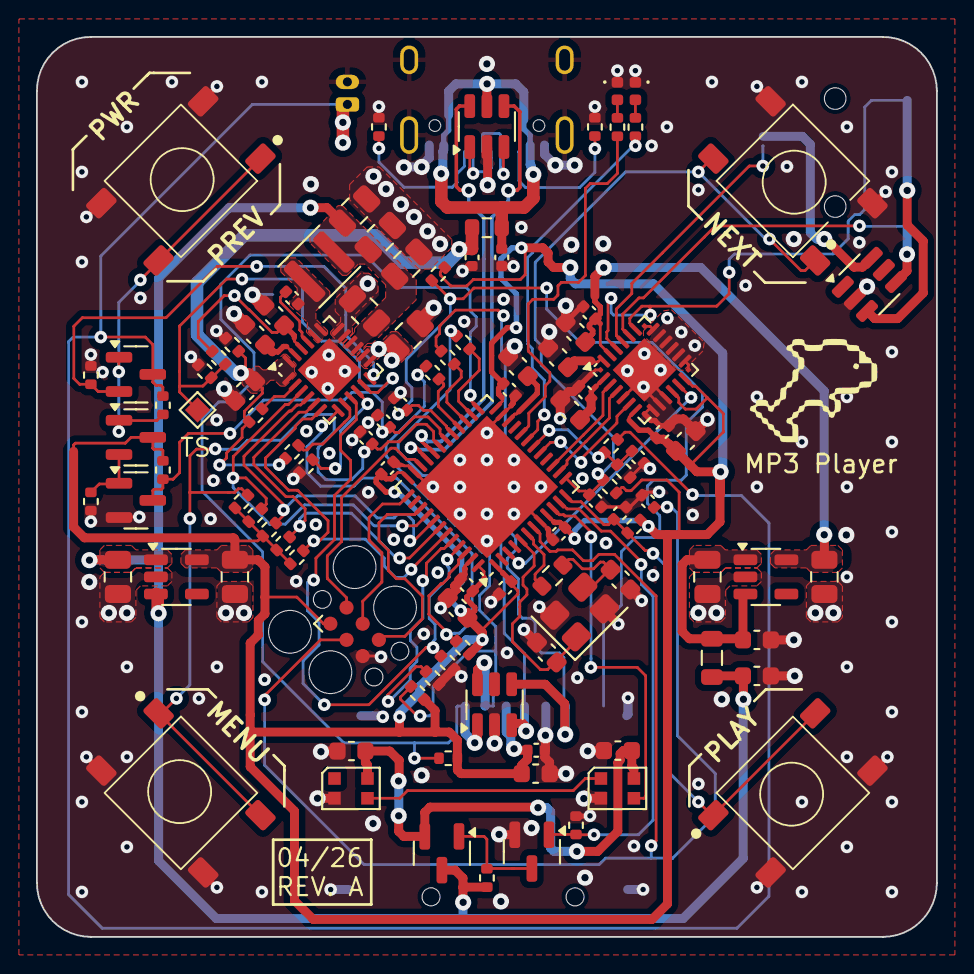
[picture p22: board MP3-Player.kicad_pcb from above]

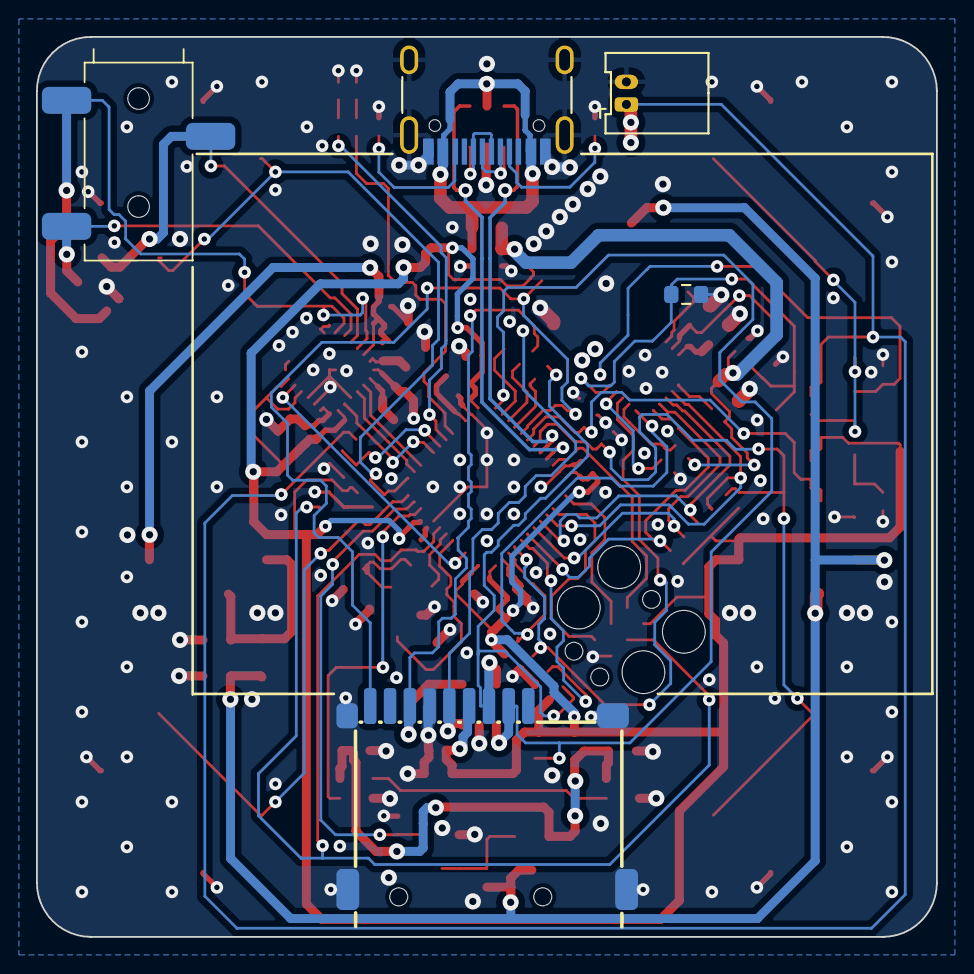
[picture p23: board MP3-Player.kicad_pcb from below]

Board: 4 copper layers, 50.0 x 50.0 mm, 111 parts (5 on the bottom side), 71 nets.

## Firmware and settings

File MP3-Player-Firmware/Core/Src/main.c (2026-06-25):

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
/* Includes ------------------------------------------------------------------*/
#include "main.h"
#include "adc.h"
#include "dma.h"
#include "fatfs.h"
#include "i2c.h"
#include "i2s.h"
#include "spi.h"
#include "tim.h"
#include "usb_otg.h"
#include "gpio.h"

/* USER CODE BEGIN Includes */
#include "bq24259.h"
#include "buttons.h"
#include "status_leds.h"
#include "ws2812b.h"
#include "sd_card_spi.h"
#include "tad5242.h"
#include "timing.h"

#include "mp3_test.h"

#include <stdint.h>
#include <string.h>
#include <math.h>
/* USER CODE END Includes */


void SystemClock_Config(void);
/**
  * @brief  The application entry point.
  * @retval int
  */
int main(void)
{

  /* MCU Configuration--------------------------------------------------------*/

  /* Reset of all peripherals, Initializes the Flash interface and the Systick. */
  HAL_Init();

  /* Configure the system clock */
  SystemClock_Config();

  /* Initialize all configured peripherals */
  MX_GPIO_Init();
  MX_DMA_Init();
  MX_I2C1_Init();
  MX_I2S1_Init();
  MX_SPI2_Init();
  MX_TIM2_Init();
  MX_USB_OTG_FS_PCD_Init();
  MX_ADC1_Init();
  MX_FATFS_Init();
  MX_TIM5_Init();
  /* USER CODE BEGIN 2 */
  bq24259_init();
  buttons_init();
  status_leds_init();
  ws2812b_init();
  tad5242_init();
  timing_init();
  /* USER CODE END 2 */

  /* Infinite loop */
  /* USER CODE BEGIN WHILE */
  // bq24259_status_t status;
  // bq24259_fault_t fault;
  status_leds_set_mode(STATUS_LED_GREEN, STATUS_LED_MODE_BLINK_SLOW);
  status_leds_set_mode(STATUS_LED_BLUE, STATUS_LED_MODE_BLINK_FAST);

  ws2812b_set_colour(WS2812B_LED_LEFT, 255, 0, 0);
  ws2812b_set_colour(WS2812B_LED_RIGHT, 0, 0, 255);
  ws2812b_set_brightness(WS2812B_LED_LEFT, 30);
  ws2812b_set_brightness(WS2812B_LED_RIGHT, 30);
  ws2812b_update();
  
  FATFS fs;
  if (f_mount(&fs, "", 1) != FR_OK) {
      HAL_Delay(100);
      HAL_NVIC_SystemReset();
  }

  mp3_test_run("the_people.mp3");

  while (1)
  {
    /* USER CODE END WHILE */

    /* USER CODE BEGIN 3 */
  }
  /* USER CODE END 3 */
}

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


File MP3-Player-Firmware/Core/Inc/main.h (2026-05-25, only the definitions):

#define DAC_GPO_Pin GPIO_PIN_14
#define DAC_GPO_GPIO_Port GPIOC
#define LEDS_PWM_Pin GPIO_PIN_0
#define LEDS_PWM_GPIO_Port GPIOA
#define LEDS_PWR_EN_Pin GPIO_PIN_1
#define LEDS_PWR_EN_GPIO_Port GPIOA
#define BUTTON_PLAY_Pin GPIO_PIN_2
#define BUTTON_PLAY_GPIO_Port GPIOA
#define BUTTON_NEXT_Pin GPIO_PIN_3
#define BUTTON_NEXT_GPIO_Port GPIOA
#define BAT_CHARGE_Pin GPIO_PIN_0
#define BAT_CHARGE_GPIO_Port GPIOB
#define LED_GREEN_Pin GPIO_PIN_1
#define LED_GREEN_GPIO_Port GPIOB
#define LED_BLUE_Pin GPIO_PIN_2
#define LED_BLUE_GPIO_Port GPIOB
#define SD_CARD_NCS_Pin GPIO_PIN_12
#define SD_CARD_NCS_GPIO_Port GPIOB
#define SD_CARD_SCK_Pin GPIO_PIN_13
#define SD_CARD_SCK_GPIO_Port GPIOB
#define SD_CARD_MISO_Pin GPIO_PIN_14
#define SD_CARD_MISO_GPIO_Port GPIOB
#define SD_CARD_MOSI_Pin GPIO_PIN_15
#define SD_CARD_MOSI_GPIO_Port GPIOB
#define SD_CARD_NCD_Pin GPIO_PIN_8
#define SD_CARD_NCD_GPIO_Port GPIOA
#define BUTTON_PREV_PWR_Pin GPIO_PIN_9
#define BUTTON_PREV_PWR_GPIO_Port GPIOA
#define BUTTON_MENU_Pin GPIO_PIN_10
#define BUTTON_MENU_GPIO_Port GPIOA
#define BAT_NPG_Pin GPIO_PIN_4
#define BAT_NPG_GPIO_Port GPIOB
#define BAT_STAT_Pin GPIO_PIN_5
#define BAT_STAT_GPIO_Port GPIOB
#define BAT_SCL_Pin GPIO_PIN_6
#define BAT_SCL_GPIO_Port GPIOB
#define BAT_SDA_Pin GPIO_PIN_7
#define BAT_SDA_GPIO_Port GPIOB
#define BAT_NCE_Pin GPIO_PIN_8
#define BAT_NCE_GPIO_Port GPIOB
#define BAT_INT_Pin GPIO_PIN_9
#define BAT_INT_GPIO_Port GPIOB

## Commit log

2025-07-28 Created USB Charger IC schematic symbol
    [DAC.kicad_sch, MCU.kicad_sch, MP3-Player.kicad_pcb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]
2025-07-29 Added all schematic symbols. Time to start wiring up!
    [DAC.kicad_sch, MP3-Player.kicad_sch, Peripherals.kicad_sch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]
2025-07-29 Finished cookie-cutter mcu routing
    [MCU.kicad_sch]
2025-08-01 Up to date
    [DAC.kicad_sch, MCU.kicad_sch, MP3-Player.kicad_pcb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]
2025-08-14 Started power schematic
    [DAC.kicad_sch, MCU.kicad_sch, MP3-Player.kicad_sch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]
2025-08-17 Adding i2c connections to charger ic as well as ntc safety logic
    [Power.kicad_sch]
2025-08-17 Added charger IC schematic circuitry
    [MCU.kicad_sch, Power.kicad_sch]
2025-11-14 Added new LDO (TPS7A20) schematic symbol and wired it up on power page for both analog and digital supplies
    [MCU.kicad_sch, Power.kicad_sch]
2025-11-14 Completed DAC circuitry
    [DAC.kicad_sch]
2025-11-16 Finished SD card connections with MCU
    [DAC.kicad_sch, MCU.kicad_sch]
2025-11-16 Added addressable LED circuitry
    [DAC.kicad_sch, MCU.kicad_sch, Peripherals.kicad_sch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]
2025-11-16 Added button circuitry
    [MCU.kicad_sch, MP3-Player.kicad_sch, Peripherals.kicad_sch]
2025-11-16 Added esd protection to audiojack and sd card. Also added jack detection on audiojack
    [DAC.kicad_sch, MCU.kicad_sch, Peripherals.kicad_sch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]
2025-11-17 Added adc pin and voltage divider to read battery voltage. Also added charging status leds, and assigned some footprints
    [DAC.kicad_sch, MCU.kicad_sch, MP3-Player.kicad_sch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]
2025-11-18 Assigned all footprints
    [DAC.kicad_sch, MCU.kicad_sch, Peripherals.kicad_sch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]
2025-11-22 Fixed all ERC errors
    [DAC.kicad_sch, MCU.kicad_sch, MP3-Player.kicad_pcb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]
2025-11-22 Imported board stackup
    [MP3-Player.kicad_pcb]
2025-11-24 Fixed all import change from schematic errors and warnings
    [DAC.kicad_sch, MP3-Player.kicad_pcb, Peripherals.kicad_sch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]
2025-11-24 Added 3D models for all components
    [54-00176.STEP, MP3-Player.kicad_pcb, MicroSD_Socket.STEP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]
2025-12-04 Near completion of layout
    [MP3-Player.kicad_pcb]
2025-12-08 Finished rough layout. New Audio jack still required
    [MP3-Player.kicad_pcb]
2025-12-13 Final Layout
    [MP3-Player.kicad_pcb]
2025-12-13 Adding GND vias
    [MP3-Player.kicad_pcb]
2026-01-25 Much better initial layout
    [DAC.kicad_sch, MCU.kicad_sch, MP3-Player.kicad_pcb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]
2026-01-26 Cleaned up layout yet again for proper routing. Started preliminary routing
    [MP3-Player.kicad_pcb, Peripherals.kicad_sch]
2026-02-02 Routing more mcu signals
    [MCU.kicad_sch, MP3-Player.kicad_pcb, Peripherals.kicad_sch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]
2026-02-05 Continuing routing
    [MP3-Player.kicad_pcb]
2026-02-25 Finished SD card routing
    [MP3-Player.kicad_pcb, MP3-Player.kicad_sch]
2026-03-08 Finished RGB LED routing
    [MP3-Player.kicad_pcb]
2026-03-09 Completed much of the USB-C charging IC power routing
    [MP3-Player.kicad_pcb]
2026-03-10 Routed button gpio signals
    [MCU.kicad_sch, MP3-Player.kicad_pcb]
2026-03-12 Finished USB power routing
    [MP3-Player.kicad_pcb]
2026-03-12 Changing JST connector footprint to fit next to usb
    [MP3-Player.kicad_pcb, Power.kicad_sch]
2026-03-13 Routed VBAT power trace in 3rd layer
    [MP3-Player.kicad_pcb, Peripherals.kicad_sch, Power.kicad_sch]
2026-03-21 Finished signal routing for charger ic
    [MP3-Player.kicad_pcb]
2026-03-22 Routed out shipping mode exit logic circuitry
    [DAC.kicad_sch, MP3-Player.kicad_pcb]
2026-03-23 Finished routing more miscellaneous signals
    [MP3-Player.kicad_pcb]
2026-03-27 Replaced THT buttons with SMT
    [MP3-Player.kicad_pcb, Peripherals.kicad_sch, tact switch SMD 6x6 mm x 4,5mm.step]
2026-03-30 Finished Audio Jack routing
    [DAC.kicad_sch, MCU.kicad_sch, MP3-Player.kicad_pcb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]
2026-04-17 Finished routinggit status! DRC needed
    [MP3-Player.kicad_pcb]
2026-04-20 Fixed all DRC errors
    [HRO_TYPE-C-31-M-12.step, MP3-Player.kicad_pcb]
2026-04-21 Added stitching vias
    [MP3-Player.kicad_pcb]
2026-04-24 Assigning JLCPCB part #'s
    [DAC.kicad_sch, MCU.kicad_sch, MP3-Player.kicad_pcb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]
2026-04-24 Added 5.25k resistor to thermistor divider network as per BQ24259 datasheet
    [MCU.kicad_sch, MP3-Player.kicad_pcb, Power.kicad_sch]
2026-04-25 Replaced JST connector with picoblade to match purchased battery
    [530480210.stp, MP3-Player.kicad_pcb, Power.kicad_sch]
2026-04-26 Fixing common mode sense node on audio output
    [DAC.kicad_sch, MP3-Player.kicad_pcb]
2026-04-27 Added JLCPCB part numbers for remaining parts
    [MCU.kicad_sch, MP3-Player.kicad_pcb, Power.kicad_sch]
2026-04-27 Ordered MP3 Playergit status! Finally :)
    [MP3-Player-B_Cu.gbr, MP3-Player-B_Mask.gbr, MP3-Player-B_Paste.gbr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]
2026-05-03 Adding component placement and BOM which were previously ignored by gitignore
    [MP3-Player.csv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]
2026-05-15 Fixing io on mx
    [MP3-Player-Firmware.ioc]
2026-05-15 Tested DAC and GPIO LEDs!
2026-05-19 Added button test code
2026-05-22 Testing USB Charger IC. Looks good
2026-05-23 Working BQ24259 driver init function
2026-05-23 Finished BQ24259 driver
2026-05-23 Tested and working BQ24259 driver!
2026-05-24 Added button driver
2026-05-24 Added button testing code
2026-05-25 Wrote and tested status led driver
2026-06-02 Added CubeMX timer PWM stock code
    [Power.kicad_sch]
2026-06-05 Working ws2812b driver :) Fantastic stuff
2026-06-05 Fixing LEFT and RIGHT RGB LED orientation in driver
    [main.c, ws2812b.c]
2026-06-16 Adding initialization status helper to SD card spi
2026-06-17 First crack at tad5242 driver with test code
    [MP3-Player-Firmware.ioc, main.c, tad5242.c]
2026-06-18 Cleaning up driver
2026-06-18 Enabling TIM5 to act as free-running profiler timer
2026-06-19 Tracking down poor audio bug
    [main.c, tad5242.c, timing.c]
2026-06-23 Broken 1kHz sin wave
    [main.c, tad5242.c]
2026-06-23 Fixed I2S frame format bug. Audio now working again
    [MP3-Player-Firmware.ioc, main.c]

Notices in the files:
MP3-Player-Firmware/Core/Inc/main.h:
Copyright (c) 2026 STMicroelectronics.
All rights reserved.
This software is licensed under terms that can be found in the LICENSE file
